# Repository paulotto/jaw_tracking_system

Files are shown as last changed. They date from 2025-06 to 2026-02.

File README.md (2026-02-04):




# JawTrackingSystem (JTS): A customizable, low-cost, optical jaw tracking system

A modular and extensible Python package for analyzing jaw motion using motion capture data. 
Designed for research and clinical applications, it provides a flexible pipeline for calibration, 
coordinate transformations, registration, smoothing, visualization, and export of jaw kinematics.
The models for the hardware components are provided as STL files and inside a FreeCAD project file.

---

## Table of Contents
- [Features](#features)
- [Hardware](#hardware)
- [Installation](#installation)
- [Quick Start](#quick-start)
- [Configuration](#configuration)
- [Setup and Usage](#setup-and-usage)
- [Extending the Framework](#extending-the-framework)
- [Documentation](#documentation)
- [Examples](#examples)
- [Directory Structure](#directory-structure)
- [Testing](#testing)
- [License](#license)
- [Citation](#citation)

---

## Features
- **Customizable Hardware**: 3D-printable, low-cost components for jaw tracking
- **Flexible Analysis Pipeline**: Calibration, relative motion, coordinate transformation, smoothing, export
- **Motion Capture Support**: Abstract base classes for Qualisys (extensible to other systems)
- **Real-time & Offline**: Supports both offline analysis and real-time streaming (in development)
- **HDF5 Analysis Tools**: 
  - Split recordings by sub-experiments with automatic frame offset handling
  - Plot derivatives (velocity, acceleration) alongside trajectories
  - Compare raw vs smoothed data with comprehensive visualization
- **Easy Configuration**: JSON-based configuration system
- **Comprehensive Testing**: Test suite for core functionality (24 tests)
- **Well Documented**: Complete API reference and examples

## Hardware
The hardware components are designed to be low-cost and customizable. The models for the hardware components are 
provided as STL files and inside a FreeCAD project file. You can find the files in the [models](models) directory.

The mouthpiece, teeth attachment, headpiece, and digitizing pointer are designed to be 3D-printed. 
Since it isn't easy to 3D-print a sharp point for the digitizing pointer, a dart point is used, which can be attached 
to a 2BA thread connected to the digitizing pointer's tip.
For the reflective markers, you can use reflective fibers or reflective tape.
The headpiece can be attached and fastened to the head using hook-and-loop tape (see [Components](#components)).

### Components
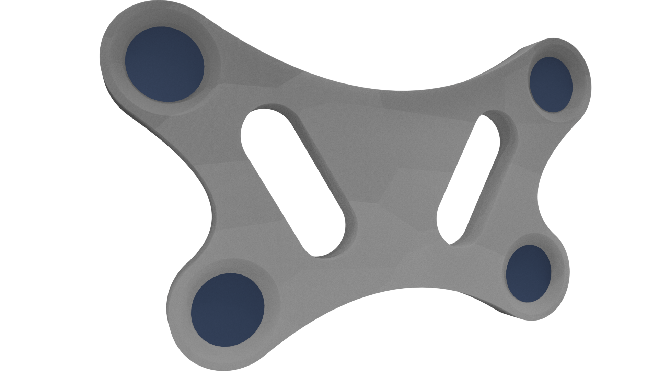
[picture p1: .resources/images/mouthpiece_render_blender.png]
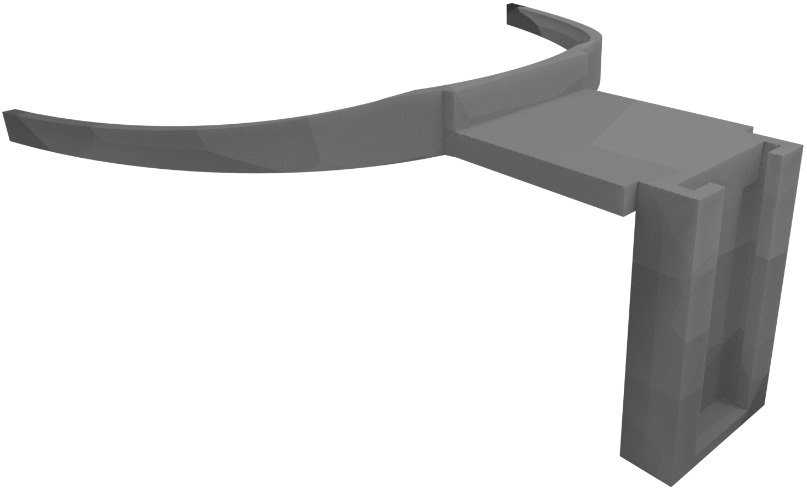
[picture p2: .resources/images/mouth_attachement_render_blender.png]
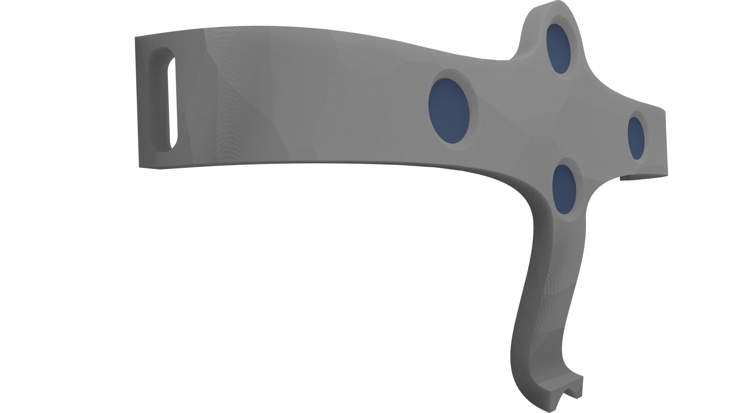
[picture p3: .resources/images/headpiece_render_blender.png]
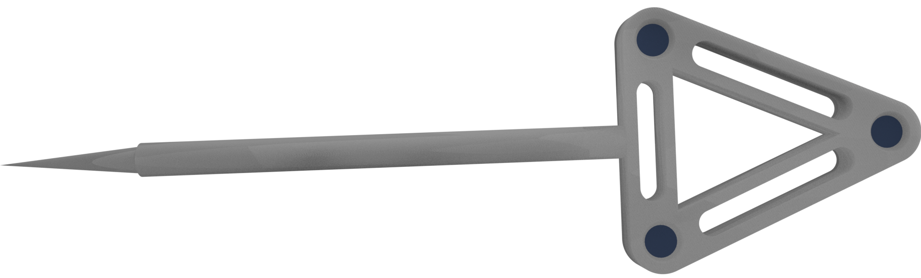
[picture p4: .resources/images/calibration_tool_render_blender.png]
|  |  |  |  |
|:---:|:---:|:---:|:---:|
| Mouthpiece | Teeth attachment | Headpiece | Digitizing pointer |

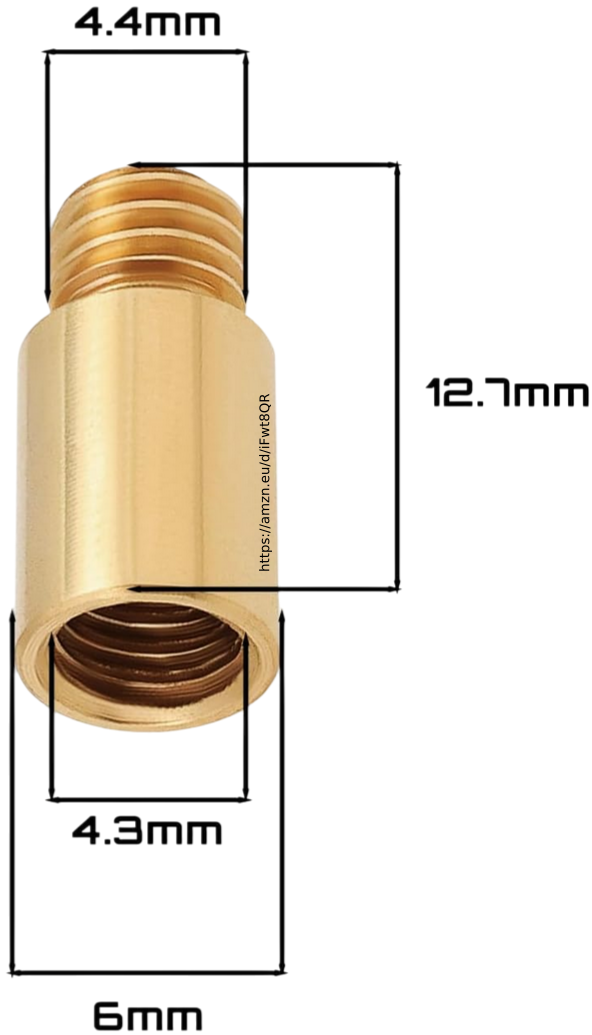
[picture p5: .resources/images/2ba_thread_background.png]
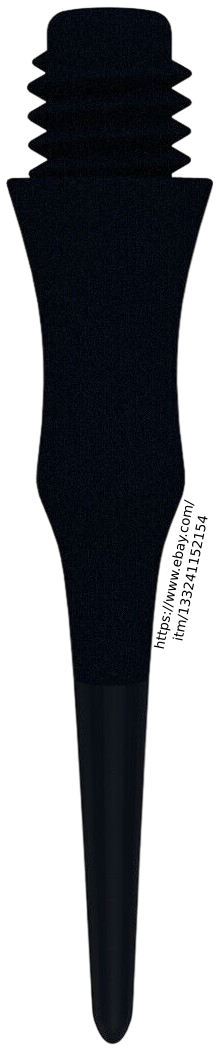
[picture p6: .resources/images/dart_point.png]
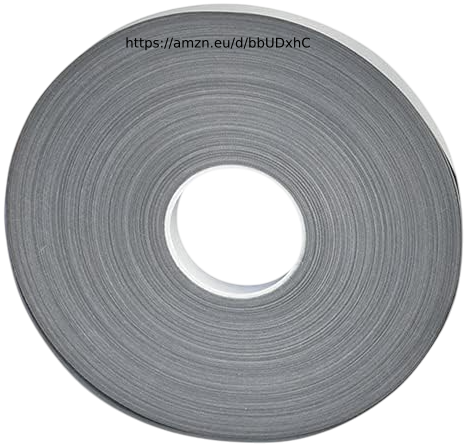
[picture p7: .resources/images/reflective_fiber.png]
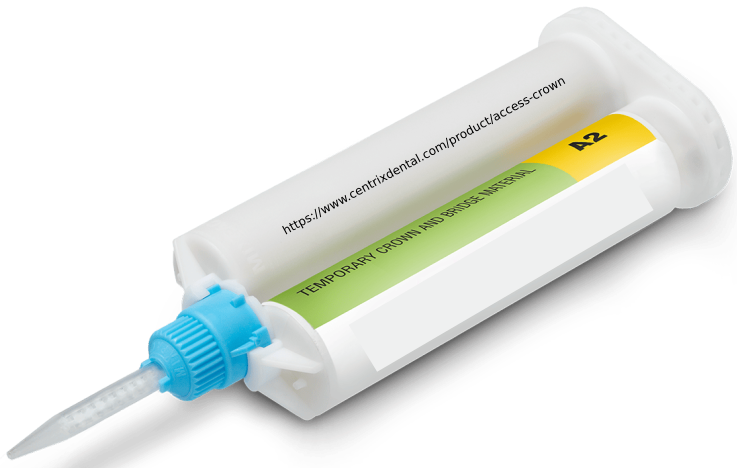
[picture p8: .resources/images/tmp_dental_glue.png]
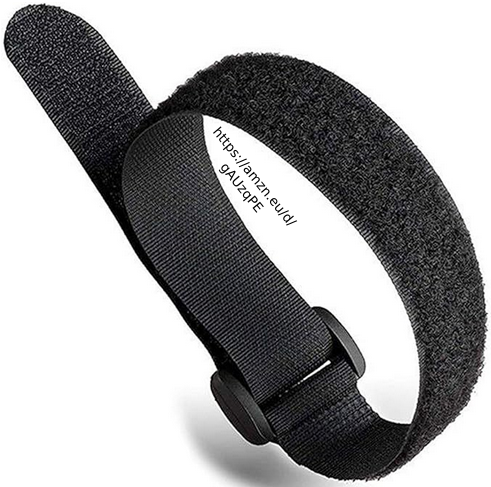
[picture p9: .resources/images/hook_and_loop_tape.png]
|  |  |  |  |  |
|:---:|:---:|:---:|:---:|:---:|
| 2BA thread | Dart point | Reflective fiber | Temporary dental glue | Hook-and-loop tape | 

## Installation

Install the package using pip:

```bash
python -m pip install jaw-tracking-system
```
From GitHub:
```bash
python -m pip install git+https://github.com/paulotto/jaw_tracking_system.git
```
Or just clone the repository, copy the `jts` directory to your project, and install the dependencies:

```bash
git clone https://github.com/paulotto/jaw_tracking_system.git 
cd jaw_tracking_system
cp -r jts your_project_directory/
python -m pip install -r requirements.txt
```

### Optional Dependencies
```bash
python -m pip install plotly==6.0.1 qtm_rt
```

## Quick Start

1. Prepare a configuration JSON file (see [README](config/README.md) for examples).
2. Run the analysis pipeline:

```bash
python -m jts.core path/to/config.json
```

3. Results (trajectories, plots, exports) will be saved to the output directory specified in your config.

## Configuration

All analysis parameters are specified in a JSON config file. Key sections include:
- `data_source`: Type (e.g., "qualisys"), filename, and system-specific parameters
- `analysis`: Calibration, experiment intervals, smoothing, coordinate transforms
- `output`: Output directory, file formats, export options
- `visualization`: Plotting options

See [config.json](config/config.json) for a template.

## Setup and Usage

This section describes the complete workflow from hardware assembly to running the analysis pipeline.

### 1. Hardware Assembly

#### 3D Printing the Components

Print the following components from the STL files in the [models/](models) directory:

| Component | STL File | Recommended Material | Notes |
|---|---|---|---|
| Mouthpiece (MTA) | [JTS_Mouth_Marker.stl](models/JTS_Mouth_Marker.stl) | Standard PLA/PETG | Attaches to teeth, must be biocompatible |
| Teeth Attachment | [JTS_Teeth_Attachment.stl](models/JTS_Teeth_Attachment.stl) | Biocompatible PETG, IBT Resin | Single-use adapter for dental glue |
| Headpiece (CRA) | [JTS_Head_Marker.stl](models/JTS_Head_Marker.stl) | Biocompatible PETG, IBT Resin | Worn on forehead |
| Digitizing Pointer (DP) | [JTS_Calibration_Tool.stl](models/JTS_Calibration_Tool.stl) | Standard PLA/PETG | Uses 2BA thread + dart point for sharp tip |

Since 3D printing a sufficiently sharp point is difficult, the digitizing pointer uses a **dart point** screwed onto a **2BA thread** that attaches to the pointer tip. This provides the precision needed for anatomical landmark digitization.

**Printing recommendations:**
- Use standard print settings for most components, adjust as needed
- For the teeth attachment and headpiece, use medical-grade biocompatible materials
- The FreeCAD project file [JTS_Models.FCStd](models/JTS_Models.FCStd) allows customization

#### Assembly

1. **Digitizing Pointer (DP):** Screw the 2BA thread into the pointer tip, then attach the dart point for precise landmark digitization.
2. **Mouthpiece (MTA):** Connect the teeth attachment to the mouthpiece. Apply reflective markers (fibers or tape) to the designated marker positions.
3. **Headpiece (CRA):** Attach reflective markers to the headpiece. Prepare hook-and-loop tape strips for securing to the forehead.

### 2. Experimental Setup

#### Motion Capture System Configuration

The system requires an optical motion capture (OMoCap) system. Our validation used:
- **System:** Qualisys Oqus with 3 cameras
- **Sampling rate:** 200 Hz
- **Post-calibration accuracy:** ~0.6 mm average

Configure your OMoCap system to track the following rigid bodies:
- `MP` - Mouthpiece/Mandibular tracking array
- `HP` - Headpiece/Cranial reference array  
- `CT` - Calibration tool/Digitizing pointer

#### Participant Preparation

1. **Attach the MTA:** Apply temporary dental glue to the teeth attachment and press firmly onto the lower incisors. Ensure robust connection without movement.
    >Advice: Dry the teeth surface with a clean cloth or air blower before applying glue for better adhesion.
2. **Secure the CRA:** Position the headpiece on the forehead and fasten with hook-and-loop tape. It should remain stable during head movements.
3. **Verify tracking:** Confirm all rigid bodies are visible and tracked by the OMoCap system.

### 3. Calibration Procedure

The system requires digitizing **six anatomical landmarks** on the teeth to define local coordinate systems:

#### Landmark Positions

| Landmark | Location | Purpose |
|---|---|---|
| `mand_point_1` | Lower left canine/premolar | Define mandibular coordinate system |
| `mand_point_2` | Lower right canine/premolar | Define mandibular coordinate system |
| `mand_point_3` | Lower central incisor | Define mandibular coordinate system |
| `max_point_1` | Upper left canine/premolar | Define maxillary coordinate system |
| `max_point_2` | Upper right canine/premolar | Define maxillary coordinate system |
| `max_point_3` | Upper central incisor | Define maxillary coordinate system |

#### Digitization Process

1. **Start recording** in your OMoCap software
2. **For each landmark:**
   - Place the DP tip precisely on the anatomical point
   - Hold steady for ~2-5 seconds
   - Note the frame interval for the configuration file (or record video for later review)
3. **Record the frame intervals** for each landmark in your config file under `analysis.calibration.mandibular.points` and `analysis.calibration.maxillary.points`

Example configuration (see [config/README.md](config/README.md) for details):
```json
"mandibular": {
  "rigid_bodies": ["MP", "CT"],
  "points": [
    {"name": "mand_point_1", "frame_interval": [2100, 2600]},
    {"name": "mand_point_2", "frame_interval": [5100, 5600]},
    {"name": "mand_point_3", "frame_interval": [7500, 8000]}
  ]
}
```

### 4. Motion Recording

After calibration, record the jaw movements of interest:

1. **Define experiment interval** in the config file under `analysis.experiment.frame_interval`
2. **Instruct participant** to perform desired movements:
   - Opening and closing
   - Protrusion and retrusion (forward/backward)
   - Lateral movements (left/right)
   - Cyclic/chewing motions
3. **Stop recording** and export data (`.mat` format for Qualisys)

### 5. Running the Analysis

#### As a Script

```bash
python -m jts.core path/to/config.json
```

Optional flags:
- `--verbose` for detailed logging
- `--plot` to show plots interactively

#### As a Library

```python
from jts.core import JawMotionAnalysis, ConfigManager

config = ConfigManager.load_config('path/to/config.json')
analysis = JawMotionAnalysis(config)
results = analysis.run_analysis()
```

#### Output

The pipeline produces:
- **HDF5 files** with transformation matrices and derivatives (velocity, acceleration)
- **Visualizations** of 3D trajectories
- **Filtered kinematic data** using bidirectional Savitzky-Golay filtering

### Real-time Streaming (Experimental)

The system supports real-time data streaming via the `streaming` configuration, but this mode has not been fully validated. For robust use, the offline workflow is recommended. See [config/README.md](config/README.md) for streaming configuration options.

## Extending the Framework

- Add new motion capture system support by subclassing `MotionCaptureData`.
- Implement new calibration or analysis routines by extending `JawMotionAnalysis`.
- Add new visualization or export utilities in `helper.py`.

## Documentation

- **[HDF5 Analysis Guide](docs/HDF5_ANALYSIS.md)** - Complete API reference for HDF5 analysis functions
- **[HDF5 Quick Start](docs/HDF5_QUICKSTART.md)** - Quick examples and common use cases  
- **[Configuration Guide](config/README.md)** - JSON configuration file reference

## Examples - Working With the Processed Data

The `examples/` directory contains scripts demonstrating key features. For comprehensive documentation, 
see **[HDF5 Analysis Guide](docs/HDF5_ANALYSIS.md)** and **[Quick Start](docs/HDF5_QUICKSTART.md)**.

### 1. Analyze HDF5 Files

Inspect, load, and visualize saved trajectory data:

```bash
python examples/hdf5_analysis_example.py output/jaw_motion.h5
```

### 2. Split by Sub-Experiments

Extract specific motion types from recordings:

```bash
python examples/split_hdf5_example.py jaw_motion.h5 config/config.json
```

This automatically:
- Detects frame offset from config (`frame_interval`)
- Splits file into sub-experiments (e.g., chewing, opening/closing)
- Recalculates derivatives for each segment

### 3. Working with HDF5 Files Programmatically

```python
import jts.helper as hlp
import matplotlib.pyplot as plt

# Inspect file structure
info = hlp.inspect_hdf5('jaw_motion.h5', verbose=True)

# Load transformation data
data = hlp.load_hdf5_transformations('jaw_motion.h5')
transforms = data['T_model_origin_mand_landmark_t']['transformations']  # (N, 4, 4)
derivatives = data['T_model_origin_mand_landmark_t']['derivatives']

# Access derivatives with convenient aliases
trans_vel = derivatives['translational_velocity']      # m/s
ang_vel = derivatives['angular_velocity']              # rad/s

# Visualize trajectory in 3D
hlp.visualize_hdf5_trajectory('jaw_motion.h5', frame_step=50)

# Compare trajectories (translations, rotations, derivatives)
hlp.compare_hdf5_trajectories('jaw_motion.h5', component='translations')
hlp.compare_hdf5_trajectories('jaw_motion.h5', component='translational_velocity')

# Split by sub-experiments
output_files = hlp.split_hdf5_by_sub_experiments(
    'jaw_motion.h5',
    config_file='config/config.json',  # Auto-detects frame_offset
    output_dir='sub_experiments/'
)

plt.show()
```

### Available HDF5 Functions

| Function | Description |
|---|---|
| `inspect_hdf5()` | Inspect file structure and metadata |
| `load_hdf5_transformations()` | Load trajectory data with derivatives |
| `visualize_hdf5_trajectory()` | Create 3D trajectory visualizations |
| `compare_hdf5_trajectories()` | Compare trajectories (translations, rotations, derivatives) |
| `split_hdf5_by_sub_experiments()` | Split files by frame intervals with auto frame offset |

**📖 For complete API reference and advanced usage, see [HDF5 Analysis Documentation](docs/HDF5_ANALYSIS.md)**

## Directory Structure

```
jaw_tracking_system/
├── jts/                              # Core package
│   ├── __init__.py
│   ├── calibration_controllers.py   # Calibration point collection
│   ├── core.py                      # Main analysis pipeline
│   ├── helper.py                    # Utility functions and HDF5 tools
│   ├── plotly_visualization.py      # Interactive 3D visualization
│   ├── precision_analysis.py        # Precision and accuracy analysis
│   ├── qualisys_streaming.py        # Real-time Qualisys streaming
│   ├── qualisys.py                  # Qualisys data interface
│   └── streaming.py                 # Abstract streaming base classes
├── config/
│   ├── README.md                    # Configuration guide
│   └── config.json                  # Configuration template
├── docs/
│   ├── HDF5_ANALYSIS.md            # Complete HDF5 API reference
│   └── HDF5_QUICKSTART.md          # Quick start guide for HDF5 tools
├── examples/
│   ├── hdf5_analysis_example.py    # HDF5 inspection and visualization
│   └── split_hdf5_example.py       # Split files by sub-experiments
├── models/                          # 3D-printable hardware models
│   ├── JTS_Calibration_Tool.stl    # Digitizing pointer
│   ├── JTS_Head_Marker.stl         # Headpiece with markers
│   ├── JTS_Models.FCStd            # FreeCAD project file
│   ├── JTS_Mouth_Marker.stl        # Mouthpiece with markers
│   └── JTS_Teeth_Attachment.stl    # Teeth attachment
├── tests/                           # Test suite (24 tests)
│   ├── __init__.py
│   ├── test_core.py
│   ├── test_helper.py
│   ├── test_precision_analysis.py
│   └── test_qualisys.py
├── CHANGELOG.md
├── CITATION.cff
├── LICENSE
├── MANIFEST.in
├── README.md
├── requirements.txt
└── setup.py
```

## Testing

Run the test suite with:

```bash
pytest tests
```

## License

This project is only intended for research and educational purposes and is licensed under the 
Attribution-NonCommercial-ShareAlike 4.0 International (CC BY-NC-SA 4.0). 
See the [LICENSE](./LICENSE) file for details.

> This license allows you to use, adapt, and distribute the material for **non-commercial** purposes,
> provided the following conditions are met:
> 1. Attribution: You must give appropriate credit to the original authors, provide a link to the license, and indicate if changes were made.
> 2. Non-Commercial: You may not use the material for commercial purposes (e.g., selling or profiting from it, directly or indirectly).
> 3. ShareAlike: If you create derivative works (e.g., modify or adapt the material), you must distribute them under the same CC BY-NC-SA 4.0 license.
> 4. No Additional Restrictions: You may not impose additional legal or technological restrictions that prevent others from exercising the rights granted by the license.

## Citation

If you use this package in your research, please cite:

```
@InProceedings{mueller2025jts,
  title={An Optical Measurement System for Open-Source Tracking of Jaw Motions},
  author={Müller, Paul-Otto and Suppelt, Sven and Kupnik, Mario and {von Stryk}, Oskar},
  booktitle = {2025 IEEE Sensors, Vancouver, Canada},
  year={2025},
  publisher = {IEEE},
  doi={10.1109/SENSORS59705.2025.11330651}
}
```

---

For more information, see the [project website](https://paulotto.github.io/projects/jaw-tracking-system/).

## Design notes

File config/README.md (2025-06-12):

# JawTrackingSystem (JTS) Configuration 
Various configurations for the JawTrackingSystem (JTS) can be easily managed through `JSON` files.
These files allow you to customize the system's behavior, such as the motion capture data source, 
analysis parameters, output settings, and visualization options.

---

## Configuration Example with Comments
The following JSON configuration file provides a comprehensive example of how to set up the JTS for jaw motion analysis
with a Qualisys motion capture system.

```json
{
  "data_source": {                        // Source and mode of motion capture data
    "type": "qualisys",                   // Type of system, e.g., "qualisys" or future types
    "mode": "offline",                    // "offline" (file-based) or "streaming" (real-time)
    "filename": "path/data.mat",          // Path to data file (required for "offline" mode)
      
    "streaming": {                        // Streaming configuration (if mode is "streaming")
      "host": "127.0.0.1",                // Host IP for streaming server
      "port": 22223,                      // Port for streaming server
      "version": "1.25",                  // Protocol version
      "buffer_size": 1000,                // Number of frames to buffer
      "timeout": 5,                       // Connection timeout in seconds
      "components": ["3d", "6d", "6deuler"], // Data components to stream
      "stream_rate": "allframes"          // Stream rate: "allframes" or specific frequency
    }
  },
    
  "analysis": {                           // Settings for analysis pipeline
    "description": "Jaw motion analysis experiment", // Description of the experiment
      
    "calibration": {                      // Calibration configuration for landmarks
      "mode": "offline",                  // "offline" or "online" calibration
        
      "online_config": {                  // Online calibration parameters
        "method": "button_triggered",     // Calibration method: "button_triggered", "automatic", or "guided"
        "stability_threshold": 0.5,       // Threshold for tool stability (mm)
        "stability_duration": 0.5,        // Duration required for stable tool (seconds)
        "capture_window": 1.0,            // Time window for capturing frames (seconds)
        "auto_capture_delay": 0.5,        // Delay before auto-capture after stability (seconds, for "automatic" mode)
        "post_capture_delay": 2.0,        // Delay after capture before next landmark (seconds, for "automatic")
        "require_confirmation": true,     // Whether to require user confirmation for capture
        "calibration_tool_name": "CT",    // Name of the calibration tool rigid body
          
        "feedback": {                     // Feedback settings for user
          "visual": true,                 // Enable visual feedback
          "audio": true,                  // Enable audio feedback
          "voice_prompts": false          // Enable voice prompts (not implemented by default)
        },
          
        "landmarks": {                    // Groups of anatomical landmarks to calibrate
          "mandibular": ["mand_point_1", "mand_point_2", "mand_point_3"],
          "maxillary": ["max_point_1", "max_point_2", "max_point_3"]
        }
      },
        
      "mandibular": {                     // Mandibular calibration details
        "rigid_bodies": ["MP", "CT"],     // Rigid bodies used for mandibular calibration
        "points": [                       // Points and frame intervals for calibration
          {
            "name": "mand_point_1",
            "frame_interval": [2100, 2600]
          },
          {
            "name": "mand_point_2",
            "frame_interval": [5100, 5600]
          },
          {
            "name": "mand_point_3",
            "frame_interval": [7500, 8000]
          }
        ]
      },
        
      "maxillary": {                      // Maxillary calibration details
        "rigid_bodies": ["HP", "CT"],     // Rigid bodies used for maxillary calibration
        "points": [                       // Points and frame intervals for calibration
          {
            "name": "max_point_1",
            "frame_interval": [9500, 10000]
          },
          {
            "name": "max_point_2",
            "frame_interval": [12100, 12600]
          },
          {
            "name": "max_point_3",
            "frame_interval": [14200, 14700]
          }
        ]
      }
    },
      
    "experiment": {                       // Main experiment configuration
      "frame_interval": [15300, 27000],   // Frame interval for the main experiment
      "use_sub_experiments": false,       // Whether to use sub-experiments
      "combine_sub_experiments": ["open_close", "chewing"], // Names of sub-experiments to combine
        
      "sub_experiments": {                // Sub-experiment definitions
        "open_close": [15300, 18400],     // Sub-experiment name and frame interval
        "left_right": [20050, 21850],
        "protrusion_retrusion": [21851, 23950],
        "chewing": [24400, 26051],
        "complex_motion": [               // Multiple intervals for complex motion
          [27000, 27500],
          [28000, 28500],
          [29000, 29500]
        ]
      },
        
      "interpolation": {                  // Settings for connecting frame intervals
        "method": "cubic",                // Interpolation method: "linear", "cubic", "slerp", "hermite", "none"
        "transition_frames": 10,          // Number of frames for smooth transitions
        "connect_intervals": true         // Whether to connect intervals with interpolation
      },
        
      "relative_motion": {                // Relative motion configuration
        "reference_body": "HP",           // Reference rigid body (e.g., maxillary head)
        "moving_body": "MP"               // Moving rigid body (e.g., mandibular point)
      },
        
      "coordinate_transform": {           // Coordinate system registration
        "enabled": true,                  // Whether to perform coordinate transformation
        "calibration_type": "maxillary",  // Which calibration points to use for registration
        "model_points": [                 // Model points corresponding to calibration points (in model coordinates)
          [-0.244678, -109.416, 101.356],
          [23.6189, -106.201, 73.9031],
          [-24.0445, -106.078, 74.1795]
        ]
      },
        
      "smoothing": {                      // Trajectory smoothing settings
        "enabled": true,                  // Whether to apply smoothing
        "window_length": 11,              // Window length for Savitzky-Golay filter
        "poly_order": 3                   // Polynomial order for filter
      },
        
      "coordinate_origin_index": 0        // Index of calibration point to use as origin
    },
      
    "visualization": {                    // Visualization settings
      "raw_data": true,                   // Show raw data plots
      "raw_data_3d": false,               // Show raw data in 3D
      "calibration_transforms": true,     // Visualize calibration transformations
      "relative_marker_motion": true,     // Show relative marker motion plots
      "landmark_motion": true,            // Show landmark motion plots
      "final_trajectory": true,           // Show final trajectory plots
      "plot_2d_components": true,         // Plot 2D trajectory components
      "plot_export_only": true,           // Only plot the trajectory to be exported
      "plot_rot_3d": false,               // Show 3D rotation visualization
      "show_plots": true,                 // Whether to display plots (interactive)
      "use_tex_font": false,              // Use LaTeX fonts in plots
        
      "plot_style": {                     // Plot style parameters
        "sample_rate": 10,                // Subsampling rate for plotting
        "linewidth": 1.5,                 // Line width for plots
        "axes_label_fontsize": 12,        // Font size for axes labels
        "axes_tick_fontsize": 10,         // Font size for axes ticks
        "title_fontsize": 14,             // Font size for title
        "legend_fontsize": 10,            // Font size for legend
        "figure_size": [12, 8],           // Figure size (width, height) in inches
        "labelpad_scale": 0.7,            // Scale factor for label padding
          
        "view_3d": {                      // 3D view settings
          "elev": 30,                     // Elevation angle
          "azim": 0,                      // Azimuth angle
          "roll": 0,                      // Roll angle
          "vertical_axis": "y"            // Vertical axis
        },
          
        "colors": ["tab:blue", "tab:orange", "tab:green", "tab:red", "tab:purple", "tab:brown"], // Color palette
        "line_styles": ["-", "--", "-.", ":"], // Line styles
          
        "grid": {                         // Grid settings
          "enabled": true,                // Enable grid
          "alpha": 0.3                    // Grid transparency
        }
      }
    }
  },
    
  "output": {                             // Output settings
    "directory": "./analysis_results",    // Output directory for results
    "save_csv": true,                     // Save trajectory as CSV
    "save_hdf5": true,                    // Save trajectory as HDF5
    "save_plots": false,                  // Save plots as images
    "save_tikz": false,                   // Save plots as TikZ (for LaTeX)
    "csv_filename": "jaw_motion",         // Base name for CSV output
    "hdf5_filename": "jaw_motion.h5",     // Name for HDF5 output file
    "store_quaternions": true,            // Store rotations as quaternions in HDF5
    "derivative_order": 2,                // Maximum derivative order to compute and store
    "scale_factor": 0.001,                // Scale factor for output units (e.g., mm to m)
    "unit": "m"                           // Output unit for translations
  }
}
```

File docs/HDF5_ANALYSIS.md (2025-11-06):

# HDF5 File Analysis Functions

This document describes the comprehensive HDF5 inspection, loading, and visualization functions available in `jts.helper`.

## Overview

The jaw tracking system saves trajectory data in HDF5 format for efficient storage and analysis. The following functions allow you to work with these files programmatically:

1. **`inspect_hdf5()`** - Inspect file structure and metadata
2. **`load_hdf5_transformations()`** - Load transformation data into memory
3. **`visualize_hdf5_trajectory()`** - Create 3D trajectory visualizations
4. **`compare_hdf5_trajectories()`** - Compare multiple trajectories (raw vs smoothed)
5. **`split_hdf5_by_sub_experiments()`** - Split files by frame intervals (sub-experiments)

## Functions

### `inspect_hdf5()`

Inspect an HDF5 file and return comprehensive information about its contents.

**Signature:**
```python
def inspect_hdf5(filename: Union[str, Path], 
                 verbose: bool = True) -> Dict[str, Dict[str, any]]
```

**Parameters:**
- `filename`: Path to HDF5 file
- `verbose`: If True, print detailed information to console

**Returns:**
Dictionary with structure information for each group

**Example:**
```python
import jts.helper as hlp

# Inspect file and print summary
info = hlp.inspect_hdf5('jaw_motion.h5')

# Access specific information
num_frames = info['T_model_origin_mand_landmark_t']['num_frames']
sample_rate = info['T_model_origin_mand_landmark_t']['sample_rate']
print(f"Loaded {num_frames} frames at {sample_rate} Hz")
```

**Output structure:**
```python
{
    'group_name': {
        'metadata': str,           # Configuration and processing info
        'sample_rate': float,      # Sample rate in Hz
        'unit': str,               # Unit of translations (e.g., 'mm')
        'num_frames': int,         # Number of frames
        'rotation_format': str,    # 'quaternion' or 'matrix'
        'derivative_order': int,   # Maximum derivative order stored
        'datasets': {              # Information about each dataset
            'translations': {'shape': tuple, 'dtype': str, 'size_mb': float},
            'rotations': {'shape': tuple, 'dtype': str, 'size_mb': float},
            ...
        }
    }
}
```

---

### `load_hdf5_transformations()`

Load transformation data from HDF5 file into memory.

**Signature:**
```python
def load_hdf5_transformations(filename: Union[str, Path],
                              group_name: Optional[str] = None,
                              as_matrices: bool = True) -> Dict[str, any]
```

**Parameters:**
- `filename`: Path to HDF5 file
- `group_name`: Specific group to load (None = load all groups)
- `as_matrices`: If True, convert quaternions to rotation matrices and construct 4x4 transformation matrices

**Returns:**
Dictionary containing transformation data for each group:
```python
{
    'group_name': {
        'transformations': np.ndarray,  # Shape (N, 4, 4) - Homogeneous transformation matrices
        'translations': np.ndarray,     # Shape (N, 3) - Translation vectors
        'rotations': np.ndarray,        # Shape (N, 3, 3) or (N, 4) - Rotation matrices or quaternions
        'sample_rate': float,           # Sample rate in Hz
        'unit': str,                    # Unit of translations
        'metadata': str,                # Metadata string
        'derivatives': dict             # Optional derivatives if stored
    }
}
```

**Example:**
```python
import jts.helper as hlp
import numpy as np

# Load all transformation groups
data = hlp.load_hdf5_transformations('jaw_motion.h5')

# Access specific group
raw_data = data['T_model_origin_mand_landmark_t']
transforms = raw_data['transformations']  # (N, 4, 4) matrices
translations = raw_data['translations']   # (N, 3) vectors
rotations = raw_data['rotations']         # (N, 3, 3) matrices

# Extract position at frame 100
position_100 = transforms[100, :3, 3]
print(f"Position at frame 100: {position_100} {raw_data['unit']}")

# Access translational derivatives
if 'translational_velocity' in raw_data['derivatives']:
    trans_vel = raw_data['derivatives']['translational_velocity']
    vel_magnitude = np.linalg.norm(trans_vel, axis=1)
    print(f"Max translational velocity: {vel_magnitude.max():.3f} {raw_data['unit']}/s")

if 'translational_acceleration' in raw_data['derivatives']:
    trans_acc = raw_data['derivatives']['translational_acceleration']
    acc_magnitude = np.linalg.norm(trans_acc, axis=1)
    print(f"Max translational acceleration: {acc_magnitude.max():.3f} {raw_data['unit']}/s²")

# Access rotational derivatives
if 'angular_velocity' in raw_data['derivatives']:
    ang_vel = raw_data['derivatives']['angular_velocity']
    ang_vel_mag = np.linalg.norm(ang_vel, axis=1)
    print(f"Max angular velocity: {ang_vel_mag.max():.3f} rad/s")

if 'angular_acceleration' in raw_data['derivatives']:
    ang_acc = raw_data['derivatives']['angular_acceleration']
    ang_acc_mag = np.linalg.norm(ang_acc, axis=1)
    print(f"Max angular acceleration: {ang_acc_mag.max():.3f} rad/s²")

# Load only quaternions (don't convert to matrices)
data_quat = hlp.load_hdf5_transformations('jaw_motion.h5', as_matrices=False)
quaternions = data_quat['T_model_origin_mand_landmark_t']['rotations']  # (N, 4)
```

---

#### `visualize_hdf5_trajectory`

Visualize a 3D trajectory from an HDF5 file with optional coordinate frames.

**Signature:**
```python
def visualize_hdf5_trajectory(
    filename: Union[str, Path],
    group_name: Optional[str] = None,
    frame_step: int = 100,
    show_frames: bool = True,
    frame_scale: Optional[float] = None,
    save_path: Optional[Union[str, Path]] = None,
    title: Optional[str] = None
) -> Tuple[Figure, Axes]
```

**Parameters:**
- `filename`: Path to HDF5 file
- `group_name`: Specific group to visualize (if `None`, uses first group)
- `frame_step`: Show coordinate frame every N frames (default: 100)
- `show_frames`: Whether to show coordinate frames along trajectory (default: `True`)
- `frame_scale`: Scale factor for coordinate frame arrows. If `None` (default), automatically calculated as 3% of trajectory range for optimal visualization
- `save_path`: Optional path to save the figure
- `title`: Plot title (auto-generated if `None`)

**Returns:**
- `(fig, ax)`: Matplotlib Figure and Axes objects

**Example:**
```python
import jts.helper as hlp
import matplotlib.pyplot as plt

# Create 3D visualization with auto-scaled coordinate frames
fig, ax = hlp.visualize_hdf5_trajectory(
    'jaw_motion.h5',
    group_name='T_model_origin_mand_landmark_t',
    frame_step=200,       # Show coordinate frame every 200 frames
    show_frames=True,
    frame_scale=None,     # Auto-calculate optimal scale (recommended)
    save_path='trajectory_3d.png'
)

plt.show()
```

**Features:**
- Trajectory path plotted as a 3D line
- Start point (green circle) and end point (red square) markers
- Optional coordinate frames showing orientation at regular intervals
- RGB arrows representing X, Y, Z axes of the coordinate frame
- Equal aspect ratio for accurate spatial representation
- Automatic scaling based on trajectory extent (when `frame_scale=None`)

---

### `compare_hdf5_trajectories()`

Compare multiple trajectories from the same HDF5 file (e.g., raw vs smoothed).

**Signature:**
```python
def compare_hdf5_trajectories(filename: Union[str, Path],
                              group_names: Optional[List[str]] = None,
                              component: str = 'translations',
                              save_path: Optional[Union[str, Path]] = None) -> Tuple[Figure, Axes]
```

**Parameters:**
- `filename`: Path to HDF5 file
- `group_names`: List of groups to compare (None = all groups)
- `component`: What to plot:
  - `'translations'` - X, Y, Z translations over time
  - `'rotations_euler'` - Roll, Pitch, Yaw (Euler angles) over time
  - `'rotations_rotvec'` - Rotation vector components over time
  - `'translational_velocity'` - Linear velocity (1st derivative)
  - `'translational_acceleration'` - Linear acceleration (2nd derivative)
  - `'angular_velocity'` - Angular velocity (1st rotational derivative)
  - `'angular_acceleration'` - Angular acceleration (2nd rotational derivative)
- `save_path`: Optional path to save the figure

**Returns:**
Matplotlib Figure and Axes objects (3 subplots)

**Example:**
```python
import jts.helper as hlp
import matplotlib.pyplot as plt

# Compare raw and smoothed trajectories - translations
fig1, axes1 = hlp.compare_hdf5_trajectories(
    'jaw_motion.h5',
    group_names=[
        'T_model_origin_mand_landmark_t',        # Raw trajectory
        'T_model_origin_mand_landmark_t_smooth'  # Smoothed trajectory
    ],
    component='translations',
    save_path='comparison_translations.png'
)

# Compare rotations (Euler angles)
fig2, axes2 = hlp.compare_hdf5_trajectories(
    'jaw_motion.h5',
    component='rotations_euler',
    save_path='comparison_rotations.png'
)

# Compare translational velocities
fig3, axes3 = hlp.compare_hdf5_trajectories(
    'jaw_motion.h5',
    component='translational_velocity',
    save_path='comparison_velocity.png'
)

# Compare angular velocities
fig4, axes4 = hlp.compare_hdf5_trajectories(
    'jaw_motion.h5',
    component='angular_velocity',
    save_path='comparison_angular_velocity.png'
)

plt.show()
```

**Features:**
- Side-by-side comparison of multiple trajectory groups
- Time-aligned plots for easy comparison
- Separate subplots for X/Y/Z components
- Automatic color coding for different trajectories
- Grid for easy reading
- Time axis in seconds (computed from sample rate)

---

## Complete Workflow Example

Here's a complete example showing a typical analysis workflow:

```python
import jts.helper as hlp
import matplotlib.pyplot as plt
from pathlib import Path

# Define file path
hdf5_file = Path('output/jaw_motion.h5')

# Step 1: Inspect the file
print("=" * 80)
print("STEP 1: Inspecting HDF5 file")
print("=" * 80)
info = hlp.inspect_hdf5(hdf5_file, verbose=True)

# Step 2: Load the data
print("\n" + "=" * 80)
print("STEP 2: Loading transformation data")
print("=" * 80)
data = hlp.load_hdf5_transformations(hdf5_file)

for group_name, group_data in data.items():
    print(f"\nGroup: {group_name}")
    print(f"  Frames: {len(group_data['transformations'])}")
    print(f"  Duration: {len(group_data['transformations']) / group_data['sample_rate']:.2f} s")

# Step 3: Visualize in 3D
print("\n" + "=" * 80)
print("STEP 3: Creating 3D visualization")
print("=" * 80)
fig1, ax1 = hlp.visualize_hdf5_trajectory(
    hdf5_file,
    frame_step=100,
    save_path='trajectory_3d.png'
)

# Step 4: Compare trajectories (if multiple groups exist)
if len(data) > 1:
    print("\n" + "=" * 80)
    print("STEP 4: Comparing trajectories")
    print("=" * 80)
    
    fig2, axes2 = hlp.compare_hdf5_trajectories(
        hdf5_file,
        component='translations',
        save_path='comparison_translations.png'
    )
    
    fig3, axes3 = hlp.compare_hdf5_trajectories(
        hdf5_file,
        component='rotations_euler',
        save_path='comparison_rotations.png'
    )

# Display all plots
plt.show()
```

---

## HDF5 File Structure

The jaw tracking system stores data in the following HDF5 structure:

```
jaw_motion.h5
├── T_model_origin_mand_landmark_t/          # Raw trajectory
│   ├── translations (N, 3)                  # Translation vectors [mm]
│   ├── rotations (N, 4) or (N, 3, 3)       # Quaternions or rotation matrices
│   ├── translational_derivative_order_1     # Velocity (if requested)
│   ├── translational_derivative_order_2     # Acceleration (if requested)
│   ├── rotational_derivative_order_1        # Angular velocity (if requested)
│   └── rotational_derivative_order_2        # Angular acceleration (if requested)
│
└── T_model_origin_mand_landmark_t_smooth/   # Smoothed trajectory (if enabled)
    ├── translations (N, 3)
    ├── rotations (N, 4) or (N, 3, 3)
    ├── ... (derivatives if requested)
```

**Group Attributes:**
- `metadata`: JSON string with configuration and processing parameters
- `sample_rate`: Sample rate in Hz (e.g., 200.0)
- `unit`: Unit of translations (e.g., 'mm', 'm')

**Dataset Information:**
- `translations`: (N, 3) array of translation vectors
- `rotations`: (N, 4) quaternions [w, x, y, z] or (N, 3, 3) rotation matrices
- `translational_derivative_order_k`: (N, 3) kth derivative of translation
- `rotational_derivative_order_k`: (N, 4) or (N, 3, 3) kth derivative of rotation

---

## Command-Line Usage

A complete example script is provided in `examples/hdf5_analysis_example.py`:

```bash
# Basic usage
python examples/hdf5_analysis_example.py output/jaw_motion.h5

# The script will:
# 1. Inspect the file structure
# 2. Load all transformation data
# 3. Create 3D trajectory visualization
# 4. Compare raw vs smoothed trajectories (if available)
# 5. Display all plots
```

---

## Tips and Best Practices

1. **Memory Management**: Large HDF5 files can consume significant memory. Use the `group_name` parameter to load only specific groups if needed.

2. **Quaternion vs Matrix**: Set `as_matrices=False` if you need quaternions for specific calculations. Matrices are more convenient for most visualization tasks.

3. **Frame Step for Coordinate Frames**: When visualizing trajectories with coordinate frames:
   - **Small datasets (<100 frames)**: Use `frame_step=5-10`
   - **Medium datasets (100-1000 frames)**: Use `frame_step=50-100`
   - **Large datasets (>1000 frames)**: Use `frame_step=200-500` or more
   - **Rule of thumb**: Aim for 10-30 coordinate frames total for clarity
   - **Example**: For 11,701 frames, use `frame_step=500` → ~23 frames (good)
   - **Too cluttered?**: Set `show_frames=False` to hide coordinate frames entirely

4. **Frame Scale**: The coordinate frame size is automatically calculated by default (`frame_scale=None`):
   - **Auto-scaling (recommended)**: Set `frame_scale=None` to automatically calculate as 3% of trajectory range
   - **Manual override**: Adjust `frame_scale` based on your trajectory extent:
     - Trajectory extent 0-10mm: `frame_scale=1.0-2.0`
     - Trajectory extent 10-100mm: `frame_scale=5.0-10.0`
     - Trajectory extent >100mm: `frame_scale=10.0-20.0`
   - **Tip**: Use auto-scaling unless you have specific visualization requirements

5. **Derivatives**: If derivatives are stored in the HDF5 file, they will be loaded automatically in the `derivatives` dictionary with convenient aliases:
   - **Translational derivatives:**
     - `'translational_velocity'` - First derivative of translation (linear velocity)
     - `'translational_acceleration'` - Second derivative of translation (linear acceleration)
   - **Rotational derivatives:**
     - `'angular_velocity'` (or `'rotational_velocity'`) - First derivative of rotation
     - `'angular_acceleration'` (or `'rotational_acceleration'`) - Second derivative of rotation
   - **Backward compatibility:** Generic aliases `'velocity'` and `'acceleration'` point to translational derivatives
   - **Original keys:** All original dataset names are preserved (e.g., `'translational_derivative_order_1'`)
   
   Example:
   ```python
   data = hlp.load_hdf5_transformations('jaw_motion.h5')
   group_data = data['T_model_origin_mand_landmark_t']
   
   # Translational derivatives
   if 'translational_velocity' in group_data['derivatives']:
       trans_vel = group_data['derivatives']['translational_velocity']
       vel_mag = np.linalg.norm(trans_vel, axis=1)
       print(f"Max translational velocity: {vel_mag.max():.3f} m/s")
   
   # Rotational derivatives
   if 'angular_velocity' in group_data['derivatives']:
       ang_vel = group_data['derivatives']['angular_velocity']
       ang_vel_mag = np.linalg.norm(ang_vel, axis=1)
       print(f"Max angular velocity: {ang_vel_mag.max():.3f} rad/s")
   ```

6. **Time Synchronization**: The sample rate is stored in the HDF5 file, allowing you to convert frame indices to timestamps:
   ```python
   data = hlp.load_hdf5_transformations('jaw_motion.h5')
   sample_rate = data['T_model_origin_mand_landmark_t']['sample_rate']
   time = np.arange(len(data['T_model_origin_mand_landmark_t']['translations'])) / sample_rate
   ```

7. **Export Formats**: Use `save_path` parameter to save plots in various formats:
   - PNG: `save_path='plot.png'` (raster, good for presentations)
   - PDF: `save_path='plot.pdf'` (vector, good for publications)
   - SVG: `save_path='plot.svg'` (vector, editable in Inkscape/Illustrator)

---

### `split_hdf5_by_sub_experiments()`

Efficiently split an HDF5 file into multiple files based on frame intervals (sub-experiments).

**Signature:**
```python
def split_hdf5_by_sub_experiments(
    filename: Union[str, Path],
    sub_experiments: Optional[Dict[str, Union[List[int], List[List[int]]]]] = None,
    config_file: Optional[Union[str, Path]] = None,
    output_dir: Optional[Union[str, Path]] = None,
    group_names: Optional[List[str]] = None,
    copy_all_groups: bool = True,
    sample_rate: Optional[float] = None,
    frame_offset: Optional[int] = None
) -> Dict[str, Path]
```

**Parameters:**
- `filename`: Path to the source HDF5 file
- `sub_experiments`: Dictionary mapping sub-experiment names to frame intervals:
  - Single interval: `{'name': [start, end]}`
  - Multiple intervals: `{'name': [[s1,e1], [s2,e2], ...]}`
  - If None, must provide `config_file`
- `config_file`: Path to config JSON file containing sub_experiments definition.
  - Must have structure: `{'analysis': {'experiment': {'sub_experiments': {...}}}}`
  - If provided, overrides `sub_experiments` parameter
  - **Auto-detects `frame_offset`** from `analysis.experiment.frame_interval[0]`
- `output_dir`: Output directory (default: same as source file)
- `group_names`: List of groups to split (default: all groups)
- `copy_all_groups`: If True, copies all groups; if False, only specified groups
- `sample_rate`: Sample rate in Hz (default: read from file)
- `frame_offset`: Offset to subtract from sub-experiment frame numbers.
  - **Use case**: When HDF5 file frames start at 0, but sub-experiments are defined in original frame numbers
  - **Example**: Original recording has frames [15300-27000], stored HDF5 has [0-11700]
    - Set `frame_offset=15300` to automatically adjust sub-experiment intervals
  - **Auto-detection**: If `config_file` is provided and contains `frame_interval`, automatically uses `frame_interval[0]`

**Returns:**
Dictionary mapping sub-experiment names to output file paths

**Example 1: Direct sub-experiments (no frame offset needed)**
```python
import jts.helper as hlp

# HDF5 frames and sub-experiments use same numbering
sub_exps = {
    'first_half': [0, 100],
    'second_half': [100, 200]
}

output_files = hlp.split_hdf5_by_sub_experiments(
    'jaw_motion.h5',
    sub_experiments=sub_exps,
    output_dir='sub_experiments/'
)
```

**Example 2: With frame offset (manual)**
```python
import jts.helper as hlp

# Original recording: frames [15300-27000]
# HDF5 file contains: frames [0-11700] (renumbered)
# Sub-experiments defined in original frame numbers

sub_exps = {
    'open_close': [15300, 18400],      # Original frame numbers
    'chewing': [24400, 26051],
}

# Automatically adjusts intervals: [15300,18400] -> [0,3100]
output_files = hlp.split_hdf5_by_sub_experiments(
    'jaw_motion.h5',
    sub_experiments=sub_exps,
    frame_offset=15300,  # Subtract 15300 from all intervals
    output_dir='sub_experiments/'
)
```

**Example 3: Load from config file (auto frame offset)**
```python
import jts.helper as hlp

# Config file contains:
# "frame_interval": [15300, 27000]  <- Auto-detects offset=15300
# "sub_experiments": {
#     "open_close": [15300, 18400],   <- Automatically adjusted
#     "chewing": [24400, 26051]
# }

output_files = hlp.split_hdf5_by_sub_experiments(
    'jaw_motion.h5',
    config_file='config/config_pm.json',  # Frame offset auto-detected!
    output_dir='sub_experiments/'
)

# Output files created:
# - sub_experiments/jaw_motion_open_close.h5 (3101 frames: [0-3100])
# - sub_experiments/jaw_motion_chewing.h5 (1652 frames: [9100-10751])

# Verify the split files
for name, path in output_files.items():
    info = hlp.inspect_hdf5(path, verbose=False)
    print(f"{name}: {info[list(info.keys())[0]]['num_frames']} frames")
```

**Key Features:**
- **Efficient**: Loads source file once, extracts multiple intervals
- **Config file support**: Load sub-experiments directly from config JSON files
- **Frame offset handling**: Automatically adjusts frame numbers when HDF5 frames don't match original numbering
- **Auto-detection**: Automatically detects frame offset from config `frame_interval`
- **Derivative recalculation**: Automatically recalculates derivatives for concatenated intervals
- **Metadata preservation**: Copies sample rate, units, and adds split metadata
- **Flexible intervals**: Supports both single intervals and multiple concatenated intervals

**Sub-Experiments in Config:**
Sub-experiments define frame intervals to extract from your recording. Useful for isolating specific motion types (e.g., chewing vs. opening/closing). When using the analysis pipeline with `use_sub_experiments: true`, only sub-experiments listed in `combine_sub_experiments` are concatenated into the final trajectory. Use `split_hdf5_by_sub_experiments()` to split an existing HDF5 file post-processing.

Config structure:
```json
{
  "analysis": {
    "experiment": {
      "frame_interval": [15300, 27000],
      "use_sub_experiments": false,
      "combine_sub_experiments": ["open_close", "chewing"],
      "sub_experiments": {
        "open_close": [15300, 18400],
        "chewing": [24400, 26051],
        "complex": [[27000, 27500], [28000, 28500]]
      }
````

**Notes:**
- Frame indices are **inclusive**: `[start, end]` includes both start and end frames
- Multiple intervals are **concatenated** in the order specified
- Derivatives are **recalculated** when intervals are concatenated to ensure continuity

---

## See Also

- `jts.plotly_visualization.JawMotionVisualizer`: For interactive Plotly-based visualizations
- `jts.helper.store_transformations()`: For creating HDF5 files programmatically
- Example scripts:
  - `examples/hdf5_analysis_example.py`: HDF5 loading and visualization
  - `examples/split_hdf5_example.py`: Splitting HDF5 files by sub-experiments

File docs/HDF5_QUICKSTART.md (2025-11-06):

# Quick Start: HDF5 Analysis Functions

## Installation
The functions are available in `jts.helper` module.

If you haven't installed the package yet, you can either:

**Option 1: Install the package**
```bash
pip install jaw-tracking-system
# or from source
pip install -e .
```

**Option 2: Add to Python path (for development)**
```python
import sys
from pathlib import Path
sys.path.insert(0, str(Path('/path/to/jaw_tracking_system')))
import jts.helper as hlp
```

**Note:** The example script `examples/hdf5_analysis_example.py` automatically handles both cases.

## Quick Usage

### 1. Inspect an HDF5 file
```python
import jts.helper as hlp

info = hlp.inspect_hdf5('jaw_motion.h5', verbose=True)
```

### 2. Load transformation data
```python
data = hlp.load_hdf5_transformations('jaw_motion.h5')

# Access data
transforms = data['T_model_origin_mand_landmark_t']['transformations']  # (N, 4, 4)
translations = data['T_model_origin_mand_landmark_t']['translations']   # (N, 3)
sample_rate = data['T_model_origin_mand_landmark_t']['sample_rate']

# Access derivatives (if available) with convenient aliases
derivatives = data['T_model_origin_mand_landmark_t']['derivatives']

# Translational derivatives
if 'translational_velocity' in derivatives:
    trans_vel = derivatives['translational_velocity']  # (N, 3)
if 'translational_acceleration' in derivatives:
    trans_acc = derivatives['translational_acceleration']  # (N, 3)

# Rotational derivatives  
if 'angular_velocity' in derivatives:
    ang_vel = derivatives['angular_velocity']  # (N, 3) or (N, 4)
if 'angular_acceleration' in derivatives:
    ang_acc = derivatives['angular_acceleration']  # (N, 3) or (N, 4)
```

### 3. Visualize in 3D
```python
import matplotlib.pyplot as plt

fig, ax = hlp.visualize_hdf5_trajectory(
    'jaw_motion.h5',
    frame_step=100,
    save_path='trajectory.png'
)
plt.show()
```

### 4. Compare trajectories
```python
# Compare raw vs smoothed - translations
hlp.compare_hdf5_trajectories(
    'jaw_motion.h5',
    component='translations',
    save_path='comparison_trans.png'
)

# Compare rotations
hlp.compare_hdf5_trajectories(
    'jaw_motion.h5',
    component='rotations_euler',
    save_path='comparison_rot.png'
)

# Compare derivatives
hlp.compare_hdf5_trajectories(
    'jaw_motion.h5',
    component='translational_velocity',
    save_path='comparison_velocity.png'
)
plt.show()
```

### 5. Split by sub-experiments
```python
# Option 1: Direct definition (no frame offset needed)
sub_exps = {
    'first_half': [0, 100],
    'second_half': [100, 200]
}
output_files = hlp.split_hdf5_by_sub_experiments(
    'jaw_motion.h5',
    sub_experiments=sub_exps,
    output_dir='sub_experiments/'
)

# Option 2: With frame offset (when HDF5 frames don't match interval numbering)
# Example: HDF5 has frames [0-11700] but sub-experiments use original [15300-27000]
sub_exps = {
    'open_close': [15300, 18400],
    'chewing': [24400, 26051]
}
output_files = hlp.split_hdf5_by_sub_experiments(
    'jaw_motion.h5',
    sub_experiments=sub_exps,
    frame_offset=15300,  # Automatically adjusts intervals
    output_dir='sub_experiments/'
)

# Option 3: From config file (auto-detects frame_offset)
# Config has: "frame_interval": [15300, 27000]
# Automatically uses 15300 as offset for sub_experiments
output_files = hlp.split_hdf5_by_sub_experiments(
    'jaw_motion.h5',
    config_file='config/config.json',  # Frame offset auto-detected!
    output_dir='sub_experiments/'
)
```

## Command-Line Tools

```bash
# Analyze HDF5 file
python examples/hdf5_analysis_example.py output/jaw_motion.h5

# Split by sub-experiments
python examples/split_hdf5_example.py jaw_motion.h5 config/config.json
```

## Full Documentation

See `docs/HDF5_ANALYSIS.md` for complete API reference and examples.

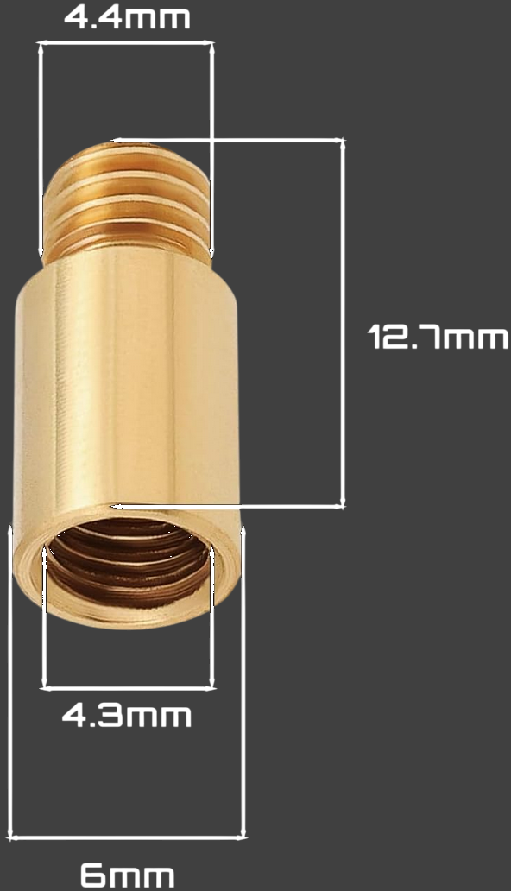
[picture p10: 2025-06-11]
.resources/images/2ba_thread.png

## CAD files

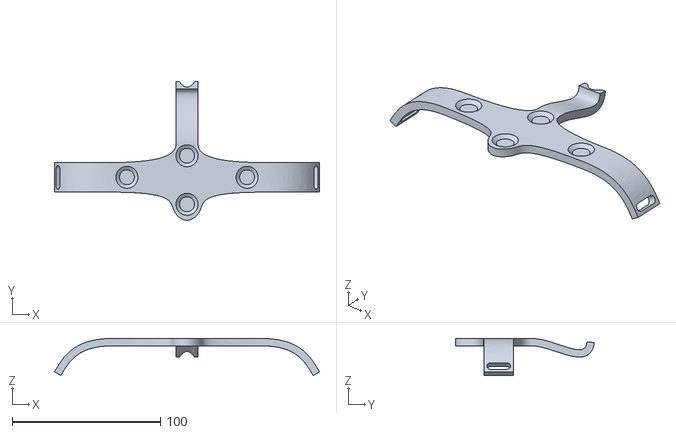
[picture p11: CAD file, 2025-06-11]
models/JTS_Head_Marker.stl
178.7 x 93.5 x 25.0

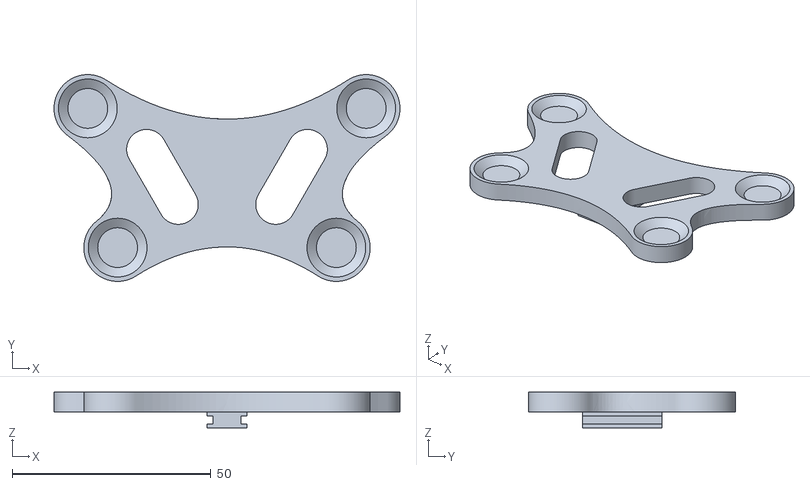
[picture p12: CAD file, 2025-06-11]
models/JTS_Mouth_Marker.stl
87.0 x 52.0 x 9.00

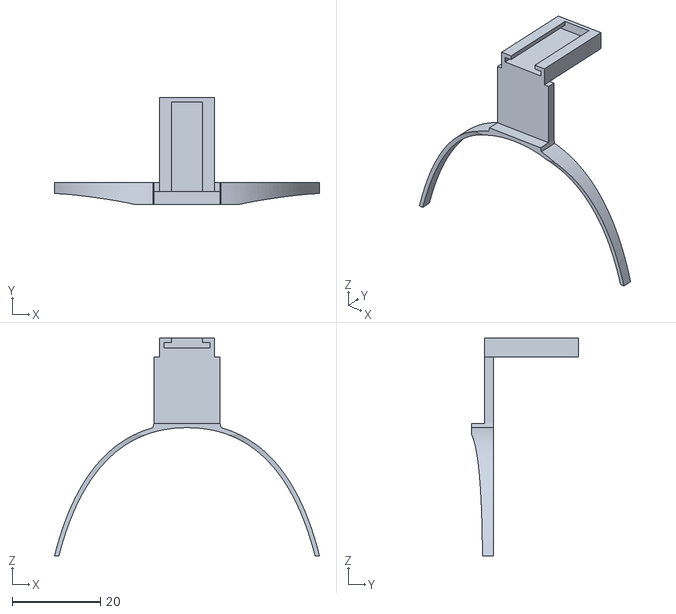
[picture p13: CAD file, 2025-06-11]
models/JTS_Teeth_Attachment.stl
60.0 x 24.2 x 49.2

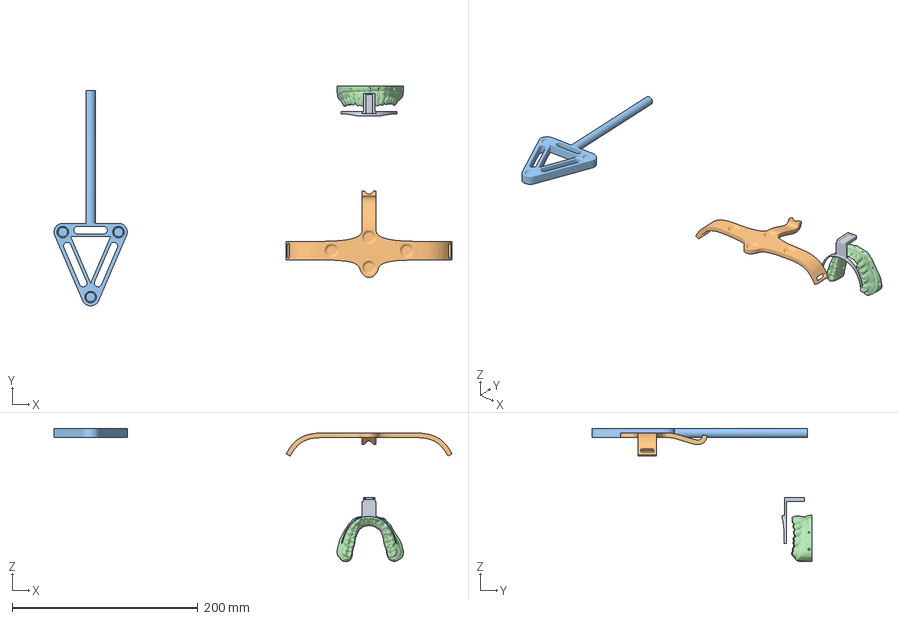
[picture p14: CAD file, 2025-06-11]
models/JTS_Models.FCStd
428.8 x 236.7 x 143.8 mm
TeethAttachement
HeadMarker
CalibrationTool
Teeth_02

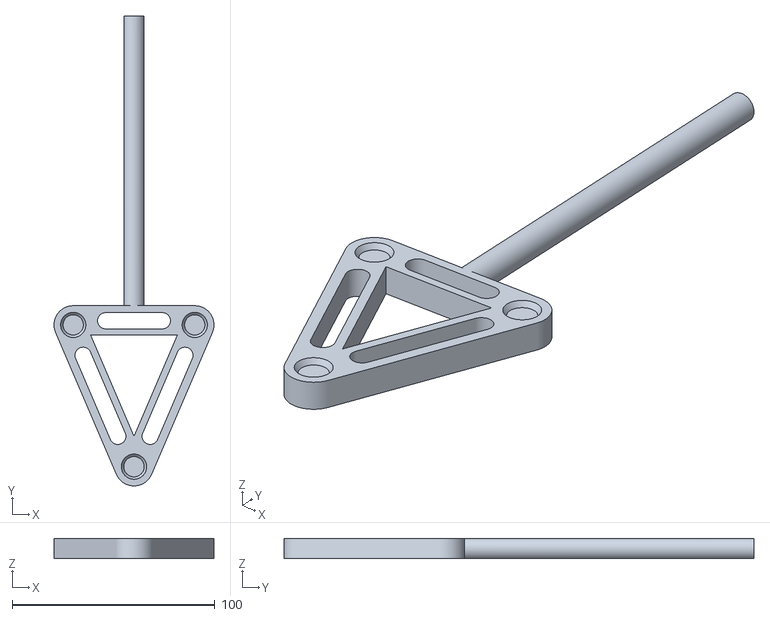
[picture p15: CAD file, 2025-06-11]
models/JTS_Calibration_Tool.stl
79.0 x 232.0 x 10.0

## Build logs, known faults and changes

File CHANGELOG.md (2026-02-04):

# Changelog

All notable changes to the Jaw Tracking System will be documented in this file.

The format is based on [Keep a Changelog](https://keepachangelog.com/en/1.0.0/),
and this project adheres to [Semantic Versioning](https://semver.org/spec/v2.0.0.html).

## [Unreleased]

---

## [1.1.1] - 2026-02-04

### Added

#### Development Tools
- **Version bump script** (`scripts/bump_version.py`): CLI tool to update version, copyright year, and date across all project files
  - Supports `--dry-run` for previewing changes
  - Auto-detects current version with `--show-current`
  - Updates 18 files: Python modules, setup.py, CITATION.cff
- **Package-level version** in `jts/__init__.py`: Access version via `import jts; jts.__version__`

#### Documentation
- **Comprehensive Setup and Usage documentation** in README.md:
  - Hardware assembly instructions with 3D printing recommendations (biocompatible materials)
  - Experimental setup guide for motion capture configuration
  - Calibration procedure with 6 anatomical landmark positions
  - Step-by-step workflow from recording to analysis
  - Hardware components table with STL file links and material specifications
  - Digitizing pointer assembly details (2BA thread + dart point)

#### HDF5 Analysis Enhancements
- **`split_hdf5_by_sub_experiments()`** in `jts/helper.py`: Split HDF5 files by frame intervals
  - Auto-detects frame_offset from config file's `frame_interval[0]`
  - Handles renumbered HDF5 frames vs original frame numbers
  - Supports single intervals and concatenated multiple intervals
  - Recalculates derivatives for concatenated segments
  - Config file and manual sub-experiment definition support
- **Derivative plotting** in `compare_hdf5_trajectories()`:
  - New components: `translational_velocity`, `translational_acceleration`
  - New components: `angular_velocity`, `angular_acceleration`
  - Proper unit handling (m/s, m/s², rad/s, rad/s²)
  - Convenient aliases for easier access to derivative data
- **HDF5 metadata improvements**:
  - Separate `config` attribute at file and group level for better reproducibility
  - File-level attributes: `creation_date`, `jts_version`, `config` (as JSON)
  - Group-level attributes: `config` (per trajectory, as JSON)
  - Easy programmatic config access: `json.loads(group.attrs['config'])`
  - Config automatically preserved when splitting files
  - Backward compatible (returns None if config missing)
- **Enhanced example script** (`examples/split_hdf5_example.py`): Demonstrates file splitting functionality
- **Updated documentation**:
  - `docs/HDF5_ANALYSIS.md`: Detailed API reference for split functionality and derivatives
  - `docs/HDF5_QUICKSTART.md`: Practical usage scenarios
  - `examples/hdf5_analysis_example.py`: Improved output formatting and derivative plots

### Changed
- Updated copyright year to 2026 across all Python modules
- Updated CITATION.cff with published IEEE Sensors 2025 DOI
- Improved README.md Hardware section with comprehensive component specifications

### Fixed
- Frame offset handling in HDF5 file splitting for accurate sub-experiment extraction

### Technical Details
- Added 10 new comprehensive tests for splitting and config storage (37 total tests, all passing)
- Enhanced HDF5 file structure with two-level metadata system

---

## [1.1.0] - 2025-10-16

### Added

#### New HDF5 Analysis Functions (`jts/helper.py`)
- **`inspect_hdf5()`**: Comprehensive HDF5 file inspection without loading all data
  - Returns detailed structure information (metadata, sample rates, units, datasets, derivatives)
  - Supports verbose and non-verbose modes
  - Memory-efficient inspection of large files

- **`load_hdf5_transformations()`**: Flexible HDF5 data loading
  - Load all groups or specific group by name
  - Automatic quaternion ↔ rotation matrix conversion
  - Returns 4x4 transformation matrices, translations, rotations, and metadata
  - Support for loading derivative data

- **`visualize_hdf5_trajectory()`**: Interactive 3D trajectory visualization
  - 3D plots with start/end markers
  - Optional coordinate frames (RGB arrows) along trajectory
  - Customizable frame step and scale
  - Save to PNG/PDF/SVG formats

- **`compare_hdf5_trajectories()`**: Multi-trajectory comparison
  - Compare raw vs smoothed trajectories
  - Support for translations, Euler angles, and rotation vectors
  - Time-aligned plots for X/Y/Z components
  - Side-by-side comparison with automatic color coding

#### Documentation
- **`docs/HDF5_ANALYSIS.md`**: Complete API reference with examples
  - Detailed function documentation
  - Usage examples for each function
  - Complete workflow examples
  - HDF5 file structure documentation
  - Tips and best practices

- **`docs/HDF5_QUICKSTART.md`**: Quick reference guide for common tasks

#### Examples
- **`examples/hdf5_analysis_example.py`**: Command-line HDF5 analysis tool
  - Demonstrates all 4 new HDF5 functions
  - Complete workflow from inspection to visualization
  - Usage: `python examples/hdf5_analysis_example.py <hdf5_file>`

#### Testing
- Added 9 comprehensive tests for new HDF5 functionality
  - `test_inspect_hdf5()`: File structure inspection
  - `test_load_hdf5_transformations_as_matrices()`: Matrix conversion
  - `test_load_hdf5_transformations_as_quaternions()`: Quaternion loading
  - `test_load_hdf5_transformations_specific_group()`: Selective loading
  - `test_load_hdf5_transformations_with_derivatives()`: Derivative handling
  - `test_visualize_hdf5_trajectory()`: 3D visualization
  - `test_compare_hdf5_trajectories_translations()`: Translation comparison
  - `test_compare_hdf5_trajectories_rotations_euler()`: Rotation comparison
  - `test_compare_hdf5_trajectories_rotations_rotvec()`: Rotation vector comparison
- Test coverage increased from 28 to 37 tests (+32%)
- All tests passing with 100% success rate

### Fixed

#### LaTeX Rendering
- **core.py**: Fixed LaTeX dependency handling
  - LaTeX now only enabled with explicit `--latex` command-line flag
  - Config file `use_tex_font` setting no longer automatically enables LaTeX
  - Prevents LaTeX errors when LaTeX is not properly installed
  - Better user control over rendering options

### Improved
- Enhanced README.md with examples section and HDF5 workflow
- Better documentation organization with dedicated HDF5 guides
- Improved user experience with optional LaTeX rendering

### Technical Details
- New functions: 4 (all with comprehensive tests)
- New tests: 9 (100% passing)
- New documentation files: 2
- Lines of code added: ~700 (functions + tests + docs)
- Test execution time: ~1.67 seconds for full suite

## [1.0.4] - 2025-10-16

### Fixed

#### Core Package (`jts/`)
- **core.py**: Fixed 15 critical type checking issues
  - Added proper `Callable` import from typing
  - Fixed type annotations for callable parameters
  - Added runtime checks for streaming-specific attributes (`load_data`, `plot_utils`, `rigid_bodies`, `frame_rate`)
  - Fixed `FrameInterval` vs `window_size` parameter compatibility between streaming and offline modes
  - Added None checks for optional motion data attributes

- **qualisys_streaming.py**: Fixed 8 critical issues
  - Added None checks before tuple unpacking from `packet.get_3d_markers()` and `packet.get_6d()`
  - Fixed event loop None checks with proper error handling
  - Fixed connection None checks before streaming operations
  - Updated `Queue.get()` API usage with proper await syntax

- **streaming.py**: Fixed 1 critical issue
  - Added None check for `stability_buffer.maxlen` before comparison to prevent potential errors

- **calibration_controllers.py**: Fixed 5 issues
  - Removed unused imports (`timedelta`, `deque`)
  - Added None checks for timestamps before operations
  - Fixed return type annotation to `Dict[str, Any]`

- **helper.py**: Fixed 13 issues
  - Fixed matplotlib type annotations (`plt.Figure` → `Figure`, `plt.Axes` → `Axes`)
  - Added `# type: ignore` for 3D axes methods not recognized by type checker
  - Fixed colormap access with proper type handling

- **precision_analysis.py**: Fixed 18 issues
  - Fixed f-string formatting issues
  - Added `# type: ignore` for h5py and scipy type checker limitations
  - Added proper type coercion for numpy types

- **plotly_visualization.py**: Fixed 23 issues
  - Removed 5 unused imports (`Tuple`, `Any`, `json`, `logging`, `pio`)
  - Fixed 2 unused variables in CLI functions (`figures`, `fig_anim`)
  - Added `# type: ignore` for 13 h5py type checker limitations
  - Fixed `kaleido` import warning with proper annotation
  - Fixed `base_name` potentially unbound issue
  - Added assertion for `trajectory_name` type safety
  - Fixed Plotly frames attribute access

- **qualisys.py**: Fixed 22 issues
  - Removed 1 unused variable (`num_bodies`)
  - Added `# type: ignore` for 13 scipy.io/h5py type checker limitations
  - Added `# type: ignore` for 8 positions/rotations subscript operations

#### Test Suite (`tests/`)
- **test_core.py**: Fixed 2 type assignment issues
  - Added `# type: ignore` for test mock assignments where `DummyMotionData` is used

- **test_helper.py**: Fixed 8 issues
  - Added `# type: ignore` for h5py type checker limitations in test assertions

- **test_qualisys.py**: Fixed 2 issues
  - Added `# type: ignore` for `.shape` attribute access on test data

### Improved
- Enhanced code quality with consistent type annotations across the entire package
- Improved error handling with proper None checks and runtime validations
- Better separation of streaming vs offline API requirements
- All type checker errors resolved (80+ issues fixed)
- All 28 unit tests passing successfully

### Technical Details
- Total issues resolved: ~80+ across 12 files
- Type checker: Pylance/Pyright
- Test coverage: 28/28 tests passing (100%)
- Python compatibility: 3.13+

## [1.0.3] - 2025-06-03

### Added
- Initial public release
- Core jaw motion analysis framework
- Qualisys motion capture integration (offline and streaming)
- Calibration and registration tools
- Precision analysis utilities
- Interactive 3D visualization with Plotly
- Comprehensive test suite

### Features
- Modular architecture for motion capture data processing
- Support for offline (.mat files) and real-time streaming (QTM RT protocol, not yet tested)
- Automatic calibration point detection and validation (not yet tested)
- Rigid body transformation analysis
- Low-pass filtering and frequency analysis
- HDF5 export with metadata preservation
- Interactive and static visualization options
- LaTeX-ready figure export

---

## Version History

- **Unreleased**: (empty)
- **1.1.1** (2026-02-04): HDF5 splitting & derivatives, metadata improvements, version management tooling, comprehensive setup documentation
- **1.1.0** (2025-10-16): New HDF5 analysis features, LaTeX rendering fixes, comprehensive testing
- **1.0.4** (2025-10-16): Major code quality improvements, type safety enhancements, all type errors resolved
- **1.0.3** (2025-06-03): Initial public release

[Unreleased]: https://github.com/paulotto/jaw_tracking_system/compare/v1.1.1...HEAD
[1.1.1]: https://github.com/paulotto/jaw_tracking_system/compare/v1.1.0...v1.1.1
[1.1.0]: https://github.com/paulotto/jaw_tracking_system/compare/v1.0.4...v1.1.0
[1.0.4]: https://github.com/paulotto/jaw_tracking_system/compare/v1.0.3...v1.0.4
[1.0.3]: https://github.com/paulotto/jaw_tracking_system/releases/tag/v1.0.3

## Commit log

2025-06-11 Add model files
    [MouthPiece-CalibrationTool.stl, MouthPiece-HeadMarker.stl, MouthPiece-MouthMarker.stl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]
2025-06-12 Rename model files
    [JTS_Calibration_Tool.stl, JTS_Head_Marker.stl, JTS_Models.FCStd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]
2025-10-16 Release v1.0.4: Fix type checking issues and improve code quality
    Resolved ~80 type checking errors across the entire codebase, improving
    type safety and code quality without breaking any existing functionality.
    Core package fixes (jts/):
    - core.py: Fixed Callable imports, streaming attribute checks (15 fixes)
    - qualisys_streaming.py: Added None checks for tuple unpacking (8 fixes)
    - streaming.py: Fixed maxlen None comparison (1 fix)
    - calibration_controllers.py: Removed unused imports (5 fixes)
    - helper.py: Fixed matplotlib type annotations (13 fixes)
    - precision_analysis.py: Added h5py/scipy type ignores (18 fixes)
    - plotly_visualization.py: Cleaned up imports and variables (23 fixes)
    - q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
2025-10-16 Add core HDF5 analysis functions
    Add four new functions for HDF5 file analysis:
    - inspect_hdf5(): Inspect file structure without loading data
    - load_hdf5_transformations(): Load with quaternion/matrix conversion
    - visualize_hdf5_trajectory(): 3D visualization with coord frames
    - compare_hdf5_trajectories(): Multi-trajectory comparison plots
2025-10-16 Add derivative plotting to compare_hdf5_trajectories()
    Extends compare_hdf5_trajectories() to support plotting derivatives:
    - Add translational_velocity and translational_acceleration components
    - Add angular_velocity and angular_acceleration components
    - Proper unit handling (m/s, m/s², rad/s, rad/s²) (might need to be adjusted when other units are used)
    - Update example script with derivative comparison plots
    - Update documentation with new component options
    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
2025-11-06 Add HDF5 splitting and derivative plotting features
    Implement comprehensive HDF5 analysis tools including file splitting by
    sub-experiments with automatic frame offset handling, and derivative
    plotting in trajectory comparison function.
    New features:
    - split_hdf5_by_sub_experiments(): Split HDF5 files by frame intervals
    - Auto-detects frame_offset from config file's frame_interval[0]
    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
2025-11-06 Add separate config attribute to HDF5 metadata for better reproducibility
    Previously, the complete configuration was embedded as a JSON string within
    the human-readable metadata attribute, making it difficult to parse
    programmatically. This commit introduces a two-level metadata structure:
    File-level attributes:
    - creation_date: ISO timestamp of file creation
    - jts_version: JTS version used to create the file
    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
2026-02-04 Add version bump script
    CLI tool to update version, copyright year, and date across all project files
    - Supports `--dry-run` for previewing changes
    - Auto-detects current version with `--show-current`
    - Updates Python modules, setup.py, CITATION.cff
2026-02-04 Comprehensive Setup and Usage documentation
    - Hardware assembly instructions with 3D printing recommendations
    - Experimental setup guide for motion capture configuration
    - Calibration procedure with anatomical landmark positions
    - Step-by-step workflow from recording to analysis
2026-02-04 Update citation with 2025 IEEE Sensors proceedings DOI
